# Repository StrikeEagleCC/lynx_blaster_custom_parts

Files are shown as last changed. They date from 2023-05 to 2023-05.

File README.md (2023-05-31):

# lynx_blaster_custom_parts
Custom parts and tools for the Lynx foam dart blaster from Orion Blasters.<br>
https://orionblasters.com/

Other good resources:<br>
Orion Blasters assembly video: https://youtu.be/wx-hrNqL2As

Out Of Darts Assembly Video: https://youtu.be/Z4hoA55K2XM

Out of Darts Tips & Tricks Video: https://youtu.be/a8z3hbgioo4

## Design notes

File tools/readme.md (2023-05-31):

## Notch Drill Guide
The notch drill guide is used to drill the notches in the end of the<br>
long aluminum bars. Press a 3/16" drill bushing into the top and some M5<br>
heat-set inserts into the bottom. Place the bars in the jig, and fasten<br>
the top down with M5x16 screws before drilling through.

Guide bushing: https://www.mcmaster.com/96511A598/<br>
Heat-set inserts: https://www.mcmaster.com/94180A361/

## Drill Marking Guides 1, 2, & 3
These marking guides are intended to be used with a 5/32" or 4mm<br>
transfer punch to mark the drill locations for all the threaded and<br>
clearance holes on the various aluminum bars.

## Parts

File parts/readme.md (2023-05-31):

## Part Notes

### Muzzle Cover.SLDPRT
- Retains barrel by engaging with front takedown pin, thus<br>
eliminating the need for thumbscrews and nuts.
- Good option for adding orange to front of blaster.

### Catch 1 (customized).SLDPRT
- changes to reduce required sear lift hight with strong springs:
  - Increased outside diameter.
  - Decreased inside diameter of hole for plunger rod nut.

### Catch 3 (customized).SLDPRT
- Increased outside diameter to reduce required sear lift height with strong springs.
- Decreased inside diameter of spring guide hole to hold spring guide straighter.
- added staggered bridging geometry to slots for aluminum bars for better printability.

### Plunger (customized).SLDPRT
- Reduced inside diameter of hole for threaded rod for better fit
- Enlarged and tapered large o-ring seat for improved sealing and priming
- Added additional curvature to small o-ring seat for better sealing and added resistance<br>
oring migration

### Ram (customized).SLDPRT
- Reduced ID of mounting screw holes for tighter positioning tolerance
- Tightened tolerance of 1/4-20 thread for better screw retention

### Sear (customized).SLDPRT
- Enlarged gear tooth that engages with trigger to reduce trigger slop
- raised latch engagement surface for reduced trigger travel and more<br>
reliable firing with strong springs.

### Tighter Rail 1 (customized).SLDPRT
- Reduced inside diameter of takedown pin hole for better fit.
- Increased thickness of wall below takedown pin hole for increased strength.

### Tighter Reciever (customized).SLDPRT
- Reduced inside diameter of plunger tube hole for better fit to reduce<br>
required sear lift height with strong springs.
- Reduced inside diameter of hole forward of plunger tube seat. I don't remember why.
- Reduced inside diameter of barrel support to reduce barrel bow when barrel shims<br>
or muzzle cover is used along with thumbscrews.

### Tighter Stock (customized).SLDPRT
- Decreased inside diameter of takedown pin holes for better fit.

### Turnaround (customized).SLDPRT
- Added dart retaining feature to reduce likelyhood of darts falling out when<br>
blaster is tipped down.

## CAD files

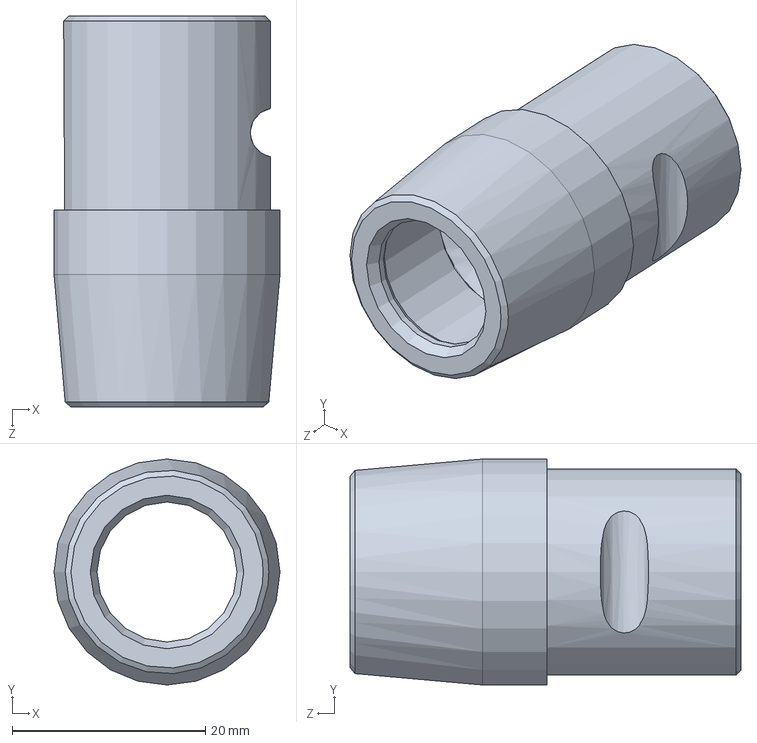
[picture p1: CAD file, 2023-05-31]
parts/Muzzle Cover.SLDPRT
23.4 x 23.4 x 40.5 mm

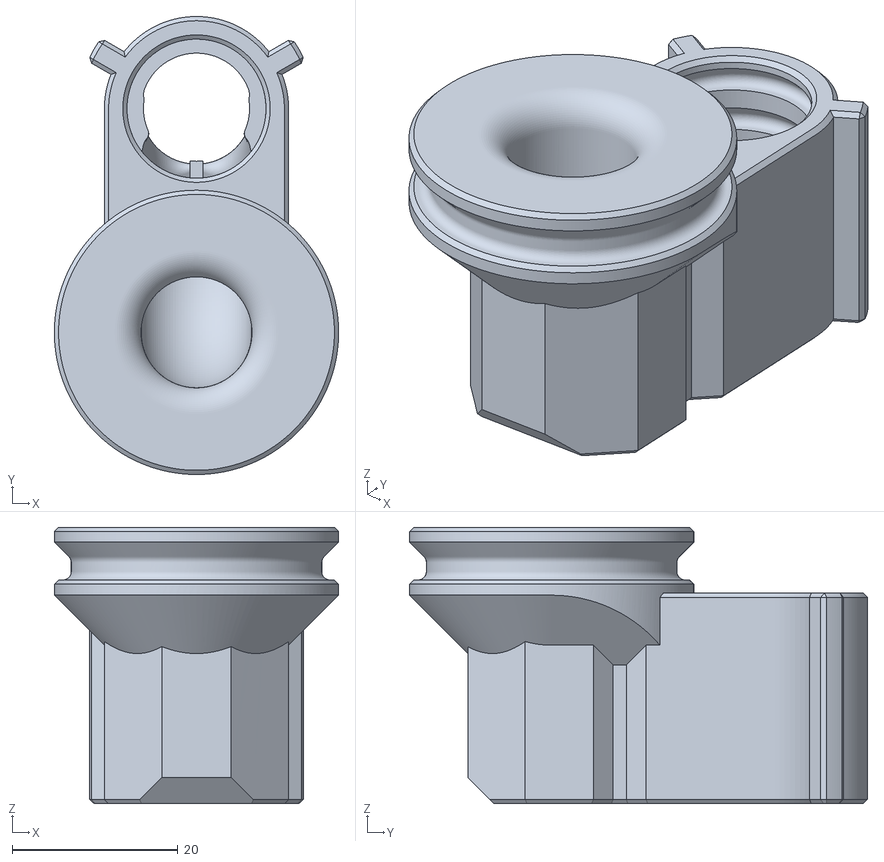
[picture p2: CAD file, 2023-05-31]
parts/Turnarounds/F Turnaround (customized).STL
34.3 x 55.2 x 33.3

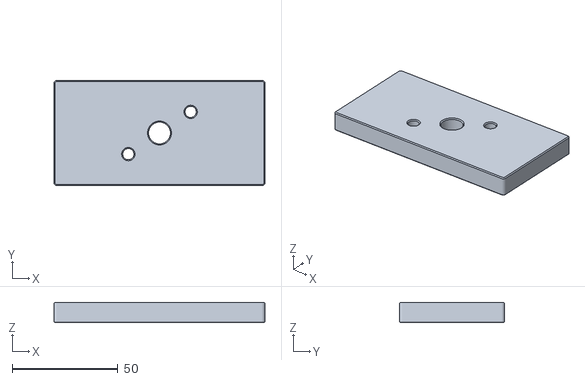
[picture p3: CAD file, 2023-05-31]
tools/Notch Drill Guide Top.STL
99.9 x 49.9 x 9.52

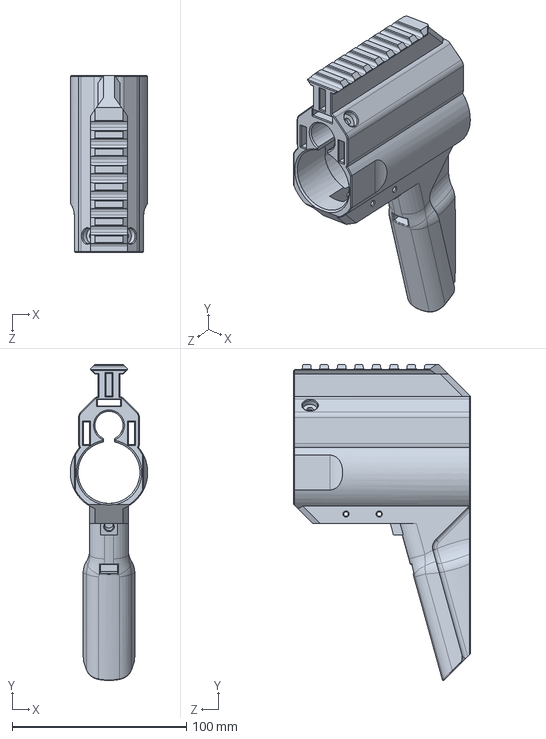
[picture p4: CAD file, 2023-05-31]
parts/Tighter Reciever (customized).SLDPRT
44.4 x 181.3 x 101.6 mm

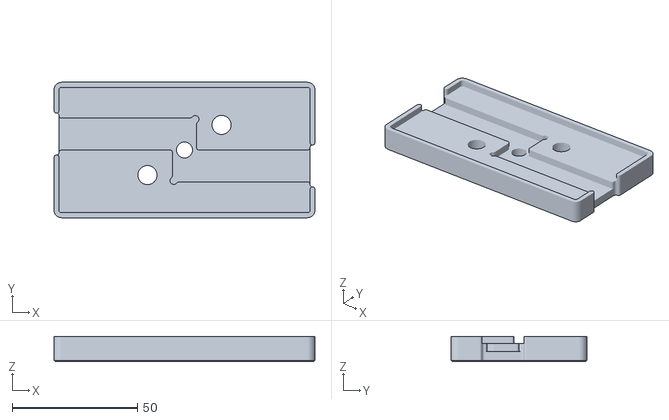
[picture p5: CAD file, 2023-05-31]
tools/Notch Drill Guide Bottom.STL
104.0 x 54.0 x 10.0

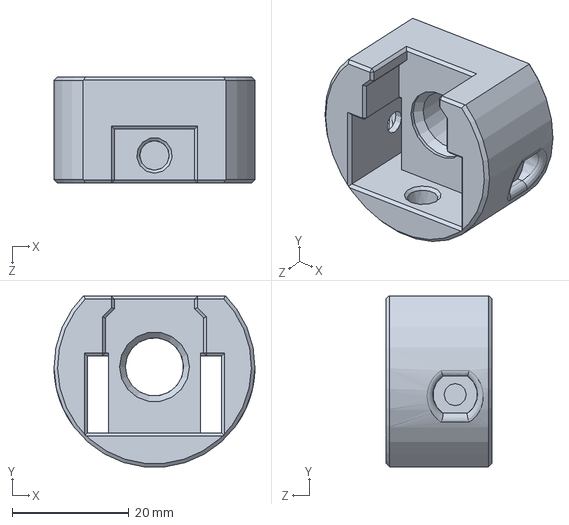
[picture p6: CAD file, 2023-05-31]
parts/Catch 1 (customized).SLDPRT
34.5 x 29.3 x 18.3 mm

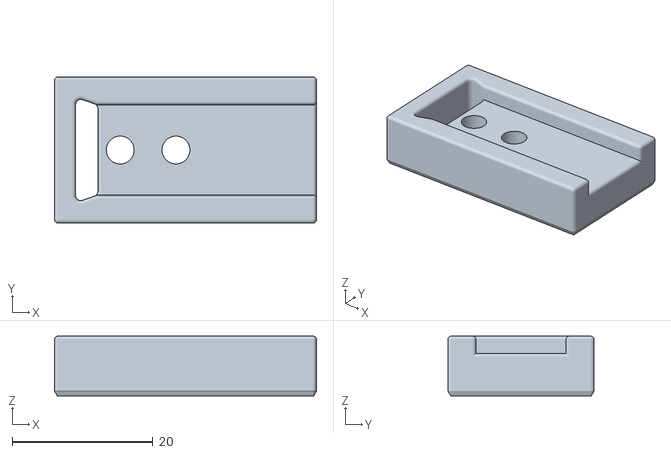
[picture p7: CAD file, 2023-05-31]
tools/Drill Marking Guide 1.STL
37.3 x 20.8 x 8.50

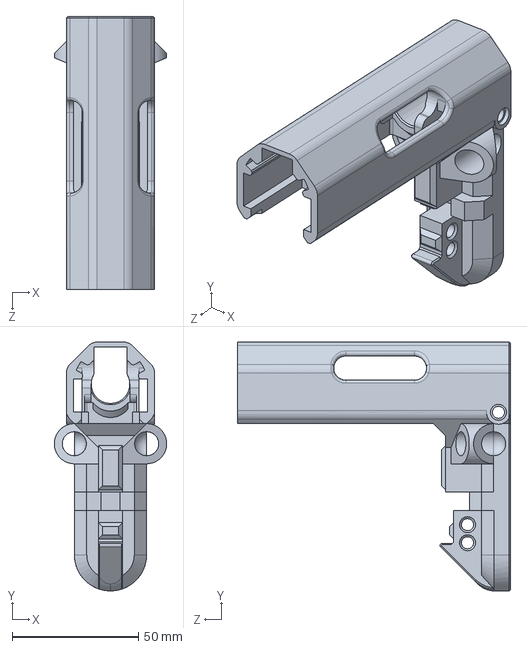
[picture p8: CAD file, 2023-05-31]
parts/Tighter Stock (customized).SLDPRT
44.4 x 98.4 x 108.0 mm

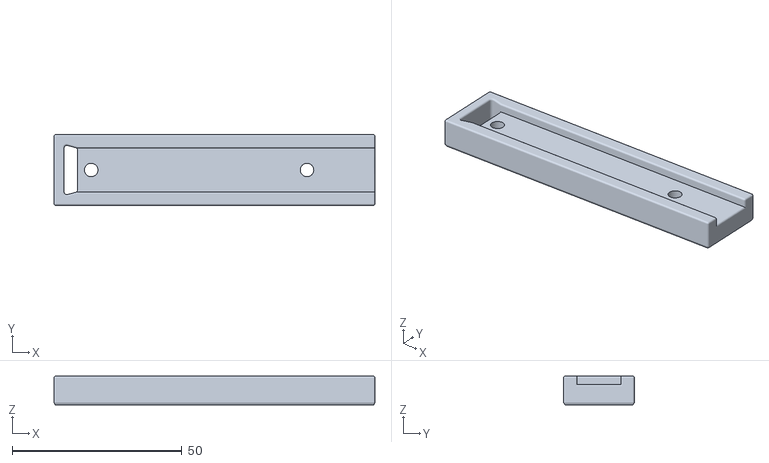
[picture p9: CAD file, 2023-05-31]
tools/Drill Marking Guide 3.STL
94.4 x 20.8 x 8.50

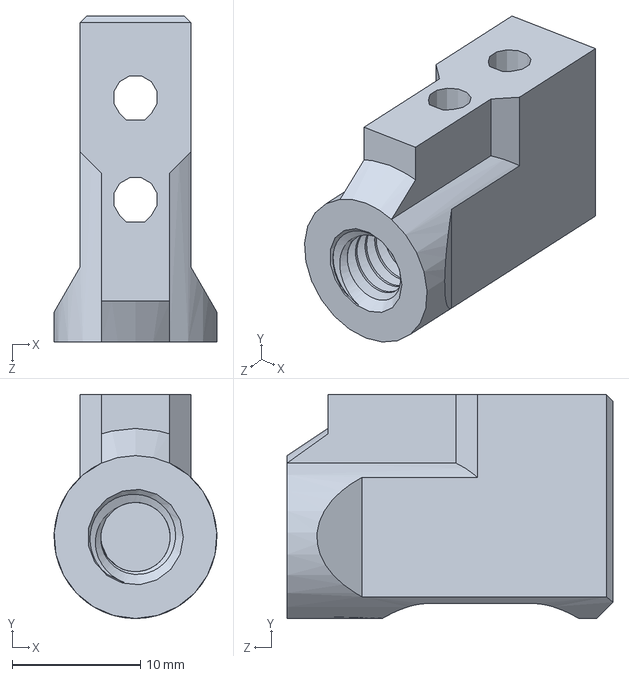
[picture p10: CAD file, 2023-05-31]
parts/Ram (customized).SLDPRT
12.7 x 17.5 x 25.4 mm

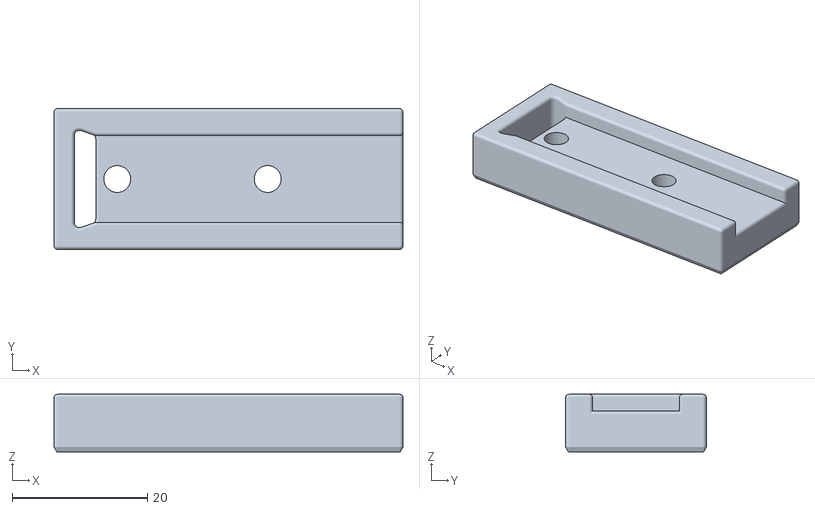
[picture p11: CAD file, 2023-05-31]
tools/Drill Marking Guide 2.STL
51.6 x 20.8 x 8.50

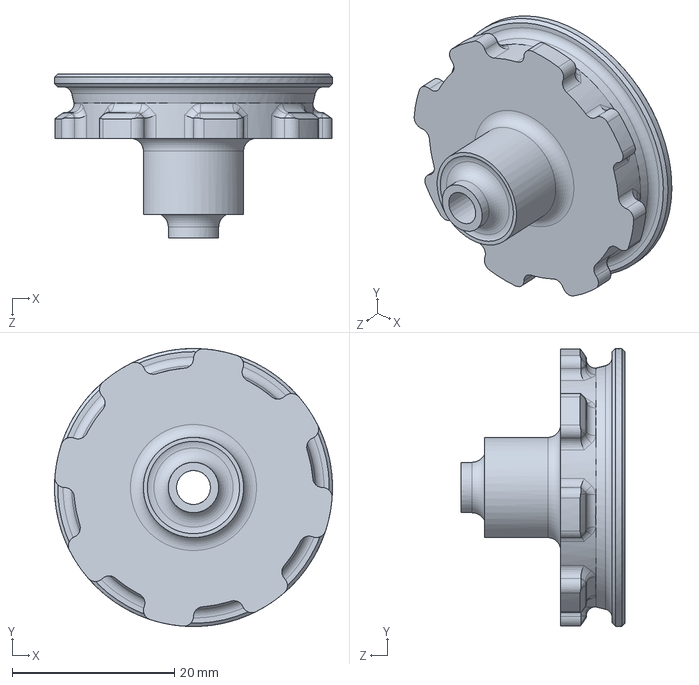
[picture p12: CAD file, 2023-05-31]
parts/Plunger (customized).SLDPRT
34.3 x 34.3 x 20.2 mm

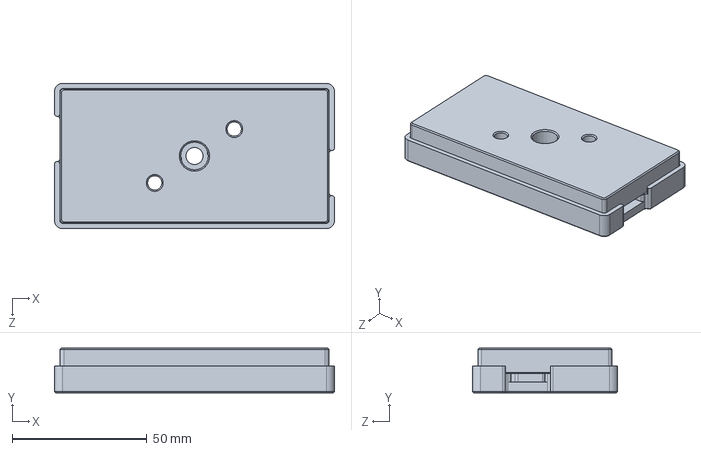
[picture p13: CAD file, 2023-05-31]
tools/Notch Drill Guide.SLDPRT
104.0 x 16.7 x 54.0 mm

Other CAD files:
parts/Turnarounds/G Turnaround (customized).STL
parts/Turnarounds/I Turnaround (customized).STL
parts/Turnarounds/Turnaround (customized).SLDPRT
parts/Turnarounds/A Turnaround (customized).STL
parts/Turnarounds/H Turnaround (customized).STL
parts/Catch 1 (customized).STL
parts/Catch 1 (customized).x_t
parts/Catch 3 (customized).SLDPRT
parts/Catch 3 (customized).STL
parts/Catch 3 (customized).x_t
parts/Muzzle Cover.STL
parts/Muzzle Cover.x_t
parts/Plunger (customized).STL
parts/Plunger (customized).x_t
parts/Ram (customized).STL
parts/Ram (customized).x_t
parts/Sear (customized).SLDPRT
parts/Sear (customized).STL
parts/Sear (customized).x_t
parts/Tighter Rail 1 (customized).SLDPRT
parts/Tighter Rail 1 (customized).STL
parts/Tighter Rail 1 (customized).x_t
parts/Tighter Reciever (customized).STL
parts/Tighter Reciever (customized).x_t
parts/Tighter Stock (customized).STL
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
